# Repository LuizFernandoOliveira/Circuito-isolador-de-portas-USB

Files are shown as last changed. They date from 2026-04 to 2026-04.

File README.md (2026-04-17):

# Circuito isolador de portas USB




## Descrição
Este circuito foi desenvolvido com o propósito de realizar uma isolação digital de 3,75 kV RMS para USB 2.0 de alta e baixa velocidade.

<p align="center">
  Imagem3
</p>

---

## Descrições técnicas

- Sinalização USB 2.0 com detecção automática de conexões de baixa, plena e alta velocidade;
- Taxas de dados de 1,5 Mbps, 12 Mbps e 480 Mbps;
- Isolador USB bidirecional para portas upstream e downstream;
- Recondicionamento e retiming de dados em alta velocidade para remoção de jitter de entrada;
- Modo de espera de ultrabaixo consumo em suspensão (L2) ou desconexão USB 2.0;
- Corrente típica de espera de baixa potência no lado upstream: 1,7 mA;
- Corrente típica de espera de baixa potência no lado downstream: 20 μA;
- Proteção ESD de ±6000 V conforme a norma IEC 61000-4-2, através da barreira de isolação;
- Atende aos requisitos de emissão da norma CISPR32/EN55032 Classe B;
- Alta imunidade a transientes de modo comum: 50 kV/μs (típico).

---

## Estrutura do repositório
Os arquivos de hardware foram desenvolvidos utilizando o KiCad 9.0.
- **`.kicad_pcb`**: Layout da placa de circuito impresso (Board).
- **`.kicad_sch`**: Esquemático eletrônico do sistema (Schematic).
- **`.kicad_pro`**: Gerenciador de projeto do KiCad (Project).

---

## Autor
**Dr. Luiz Fernando Pinto de Oliveira**

*Engenheiro Eletrônico especializado em Sistemas Embarcados e Ultra-Low Power.*
- **Website:** [FAPLO](https://faplo.webnode.page/)
- **LinkedIn:** [lfpo](https://www.linkedin.com/in/lfpo/)

---

Shield: [][cc-by-nc-nd]

This work is licensed under a
[Creative Commons Attribution-NonCommercial-NoDerivs 4.0 International License][cc-by-nc-nd].

[][cc-by-nc-nd]

[cc-by-nc-nd]: http://creativecommons.org/licenses/by-nc-nd/4.0/
[cc-by-nc-nd-image]: https://licensebuttons.net/l/by-nc-nd/4.0/88x31.png
[cc-by-nc-nd-shield]: https://img.shields.io/badge/License-CC%20BY--NC--ND%204.0-lightgrey.svg

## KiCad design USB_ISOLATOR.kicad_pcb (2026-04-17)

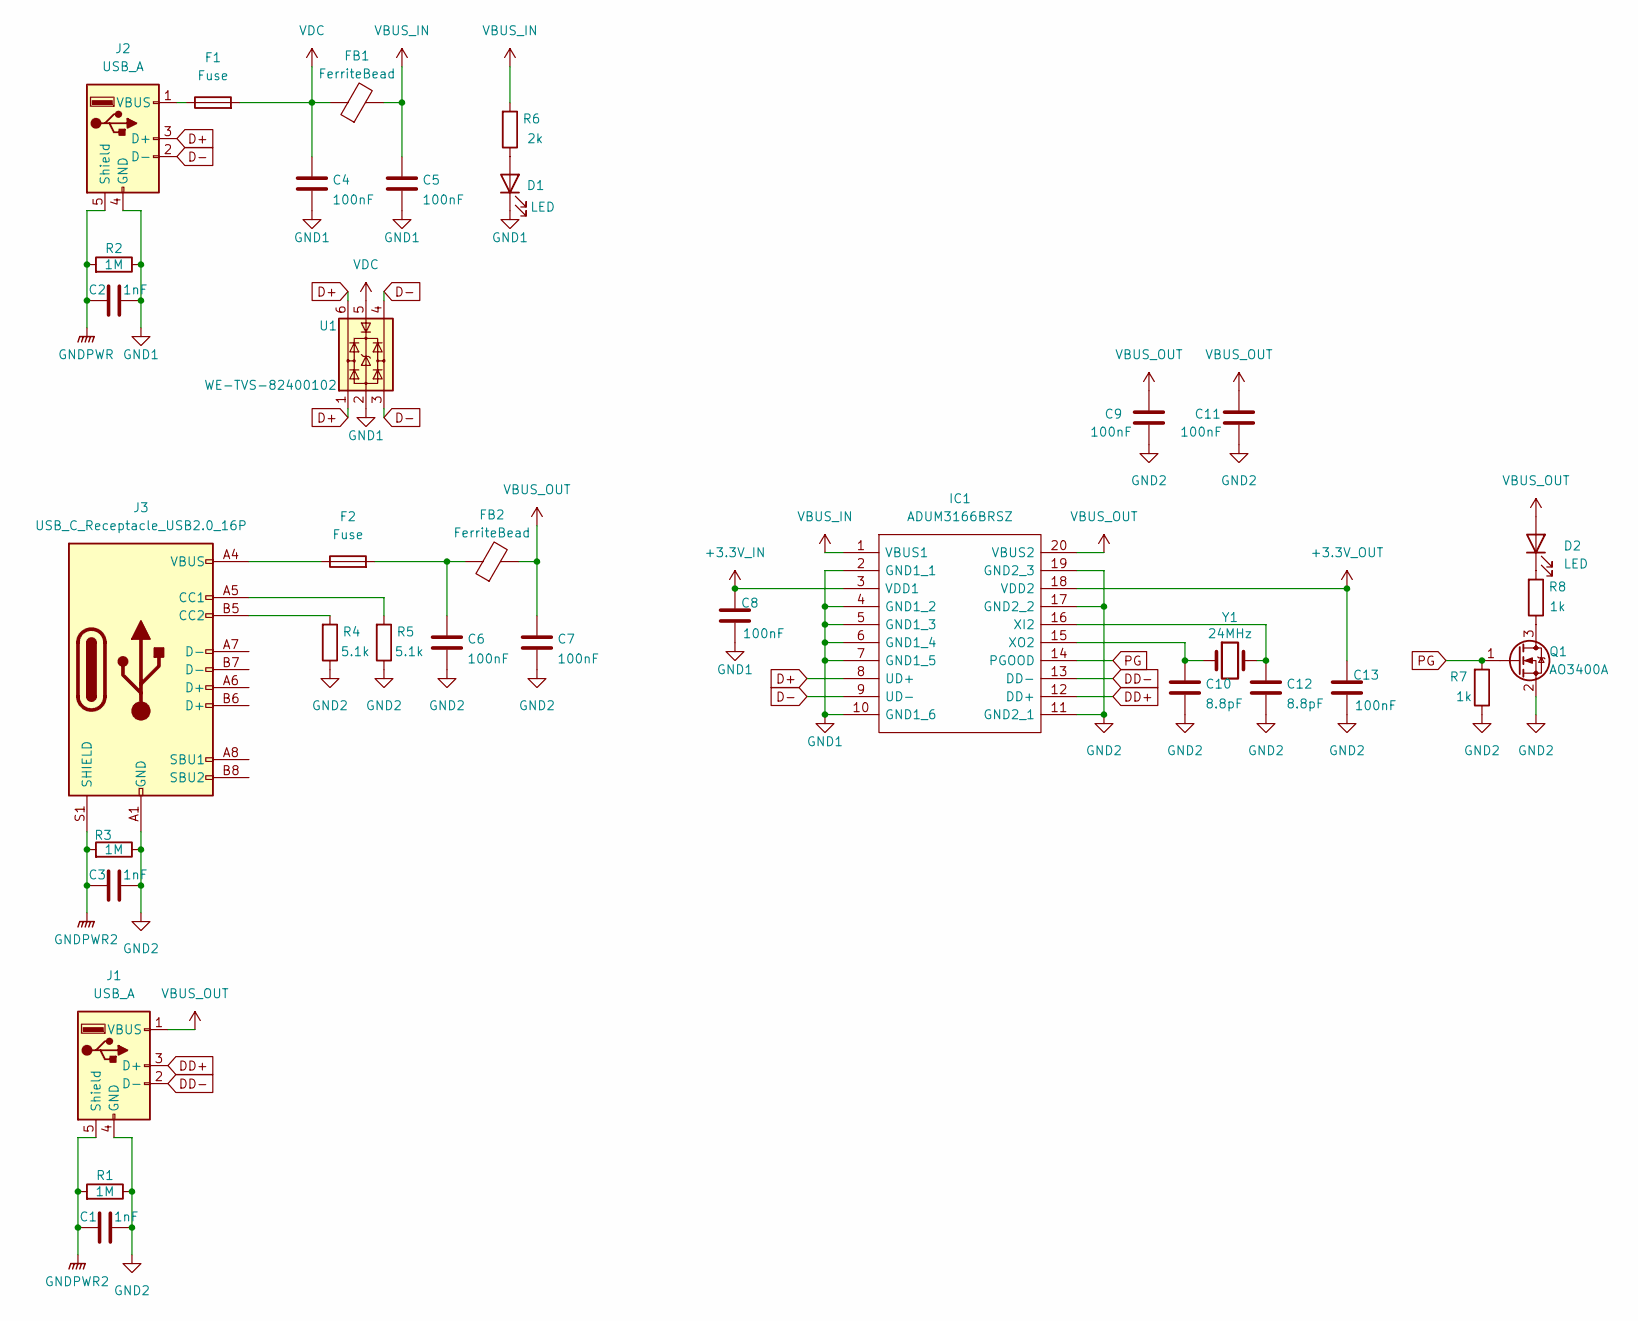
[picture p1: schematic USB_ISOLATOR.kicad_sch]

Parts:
C1, C2, C3: 1nF; C_0805_2012Metric
C4, C5, C6, C7, C8, C9, C11, C13: 100nF; C_0805_2012Metric
C10, C12: 8.8pF; C_0805_2012Metric
D1, D2: LED; LED_0805_2012Metric
F1, F2: Fuse; Fuse_0805_2012Metric
FB1, FB2: FerriteBead; L_0805_2012Metric
IC1: ADUM3166BRSZ; SOP65P780X200-20N; Manufacturer_Part_Number ADUM3166BRSZ; Mouser Part Number 584-ADUM3166BRSZ
J1: USB_A; USB_A_TE_292303-7_Horizontal
J2: USB_A; USB_A_CNCTech_1001-011-01101_Horizontal
J3: USB_C_Receptacle_USB2.0_16P; USB_C_Receptacle_HRO_TYPE-C-31-M-12
Q1: AO3400A; SOT-23
R1, R2, R3: 1M; R_0805_2012Metric
R4, R5: 5.1k; R_0805_2012Metric
R6: 2k; R_0805_2012Metric
R7, R8: 1k; R_0805_2012Metric
U1: WE-TVS-82400102; SOT-23-6
Y1: 24MHz; R_0805_2012Metric

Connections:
+3.3V_IN: C8.1, IC1.3 (VDD1)
+3.3V_OUT: C13.1, IC1.18 (VDD2)
D+: IC1.8 (UD+), J2.3 (D+), U1.1, U1.6
D-: IC1.9 (UD-), J2.2 (D-), U1.3, U1.4
DD+: IC1.12 (DD+), J1.3 (D+)
DD-: IC1.13 (DD-), J1.2 (D-)
GND1: C2.2, C4.2, C5.2, C8.2, D1.1 (K), IC1.2 (GND1_1), IC1.4 (GND1_2), IC1.5 (GND1_3), IC1.6 (GND1_4), IC1.7 (GND1_5), IC1.10 (GND1_6), J2.4 (GND), R2.1, U1.2
GND2: C1.2, C3.2, C6.2, C7.2, C9.2, C10.2, C11.2, C12.2, C13.2, IC1.11 (GND2_1), IC1.17 (GND2_2), IC1.19 (GND2_3), J1.4 (GND), J3.A1 (GND), J3.A12 (GND), J3.B1 (GND), J3.B12 (GND), Q1.2 (S), R1.1, R3.1, R4.1, R5.1, R7.1
GNDPWR: C2.1, J2.5 (Shield), R2.2
GNDPWR2: C1.1, C3.1, J1.5 (Shield), J3.S1 (SHIELD), R1.2, R3.2
unnamed: C6.1, F2.2, FB2.1
unnamed: D1.2 (A), R6.1
unnamed: D2.1 (K), R8.2
unnamed: F2.1, J3.A4 (VBUS), J3.A9 (VBUS), J3.B4 (VBUS), J3.B9 (VBUS)
unnamed: C12.1, IC1.16 (XI2), Y1.2
unnamed: C10.1, IC1.15 (XO2), Y1.1
unnamed: F1.1, J2.1 (VBUS)
unnamed: J3.A5 (CC1), R5.2
unnamed: J3.B5 (CC2), R4.2
unnamed: Q1.3 (D), R8.1
PG: IC1.14 (PGOOD), Q1.1 (G), R7.2
VBUS_IN: C5.1, FB1.2, IC1.1 (VBUS1), R6.2
VBUS_OUT: C7.1, C9.1, C11.1, D2.2 (A), FB2.2, IC1.20 (VBUS2), J1.1 (VBUS)
VDC: C4.1, F1.2, FB1.1, U1.5

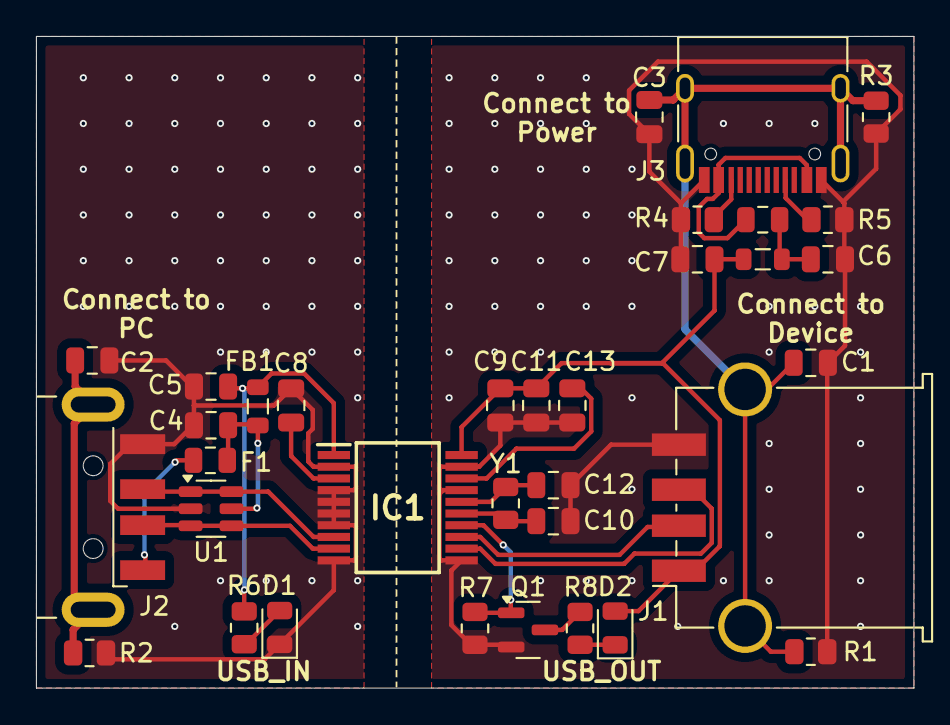
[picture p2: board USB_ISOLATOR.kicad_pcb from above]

Board: 2 copper layers, 48.8 x 36.2 mm, 34 parts (0 on the bottom side), 24 nets.

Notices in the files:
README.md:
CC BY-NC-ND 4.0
